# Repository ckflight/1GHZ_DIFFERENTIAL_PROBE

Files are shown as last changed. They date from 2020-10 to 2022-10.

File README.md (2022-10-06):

# 1GHZ DIFFERENTIAL PROBE

Instead of paying a few thousand $ to the unnecessarily expensive probes from tektronix or rigol for daily use, i made a Differential Probe which cost
15$ for 4 layer pcb and 45$ for components and it works just fine.

Mosfet source follower is used as voltage buffer which has 20dB attenuation (1/10) and an opamp subtractor is used at the end. Copper pour at the input of the pcb is removed to reduce input capacitance of the probe for high speed signals. 2 passive LPF is used at the output of Switching Regulator which is generating ripple noise. Also input power from the USB Connector is filtered with 180 Ohm Ferrite Bead which is the input of the Switching Regulator. This way of filtering
is the best way of reducing ripple noise and switching peaks of the regulator. However using second LDO Regulator to filter out instead of using switching regulator is the best option for power filtering which means better high speed signal performance.

Design needs usb input power for powering the circuit and 50 Ohm SMA connector
is used. BNC 50 Ohm feedthrough connector can be used for connection to Oscilloscope if it does not have 50 Ohm option.

1 GHz

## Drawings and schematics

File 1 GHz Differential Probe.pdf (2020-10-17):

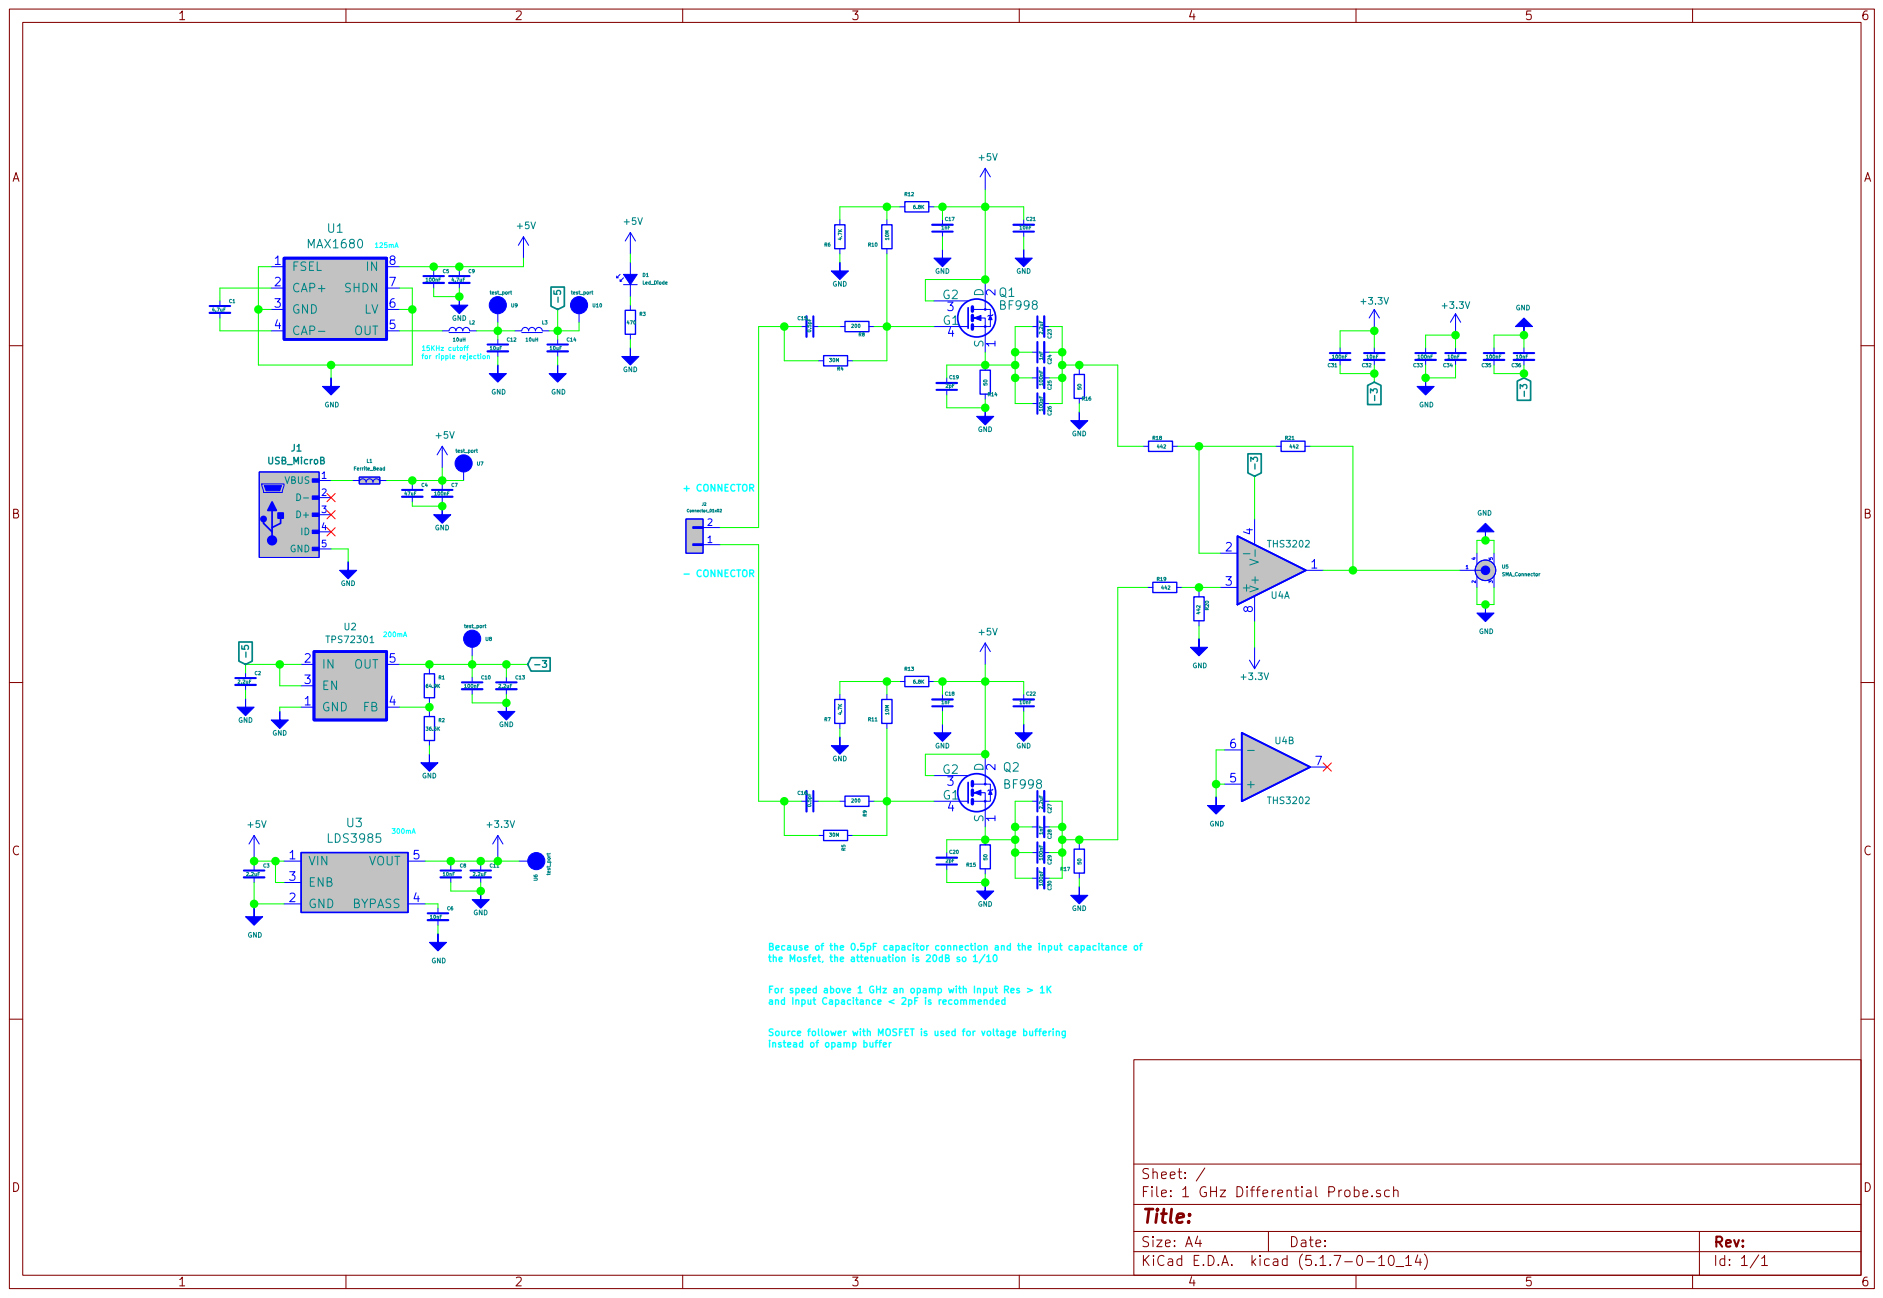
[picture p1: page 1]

15KHz cutoff for ripple rejection

the Mosfet, the attenuation is 20dB so 1/10

Source follower with MOSFET is used for voltage buffering
instead of opamp buffer

Id: 1/1 Title: File: 1 GHz Differential Probe.sch Sheet: /

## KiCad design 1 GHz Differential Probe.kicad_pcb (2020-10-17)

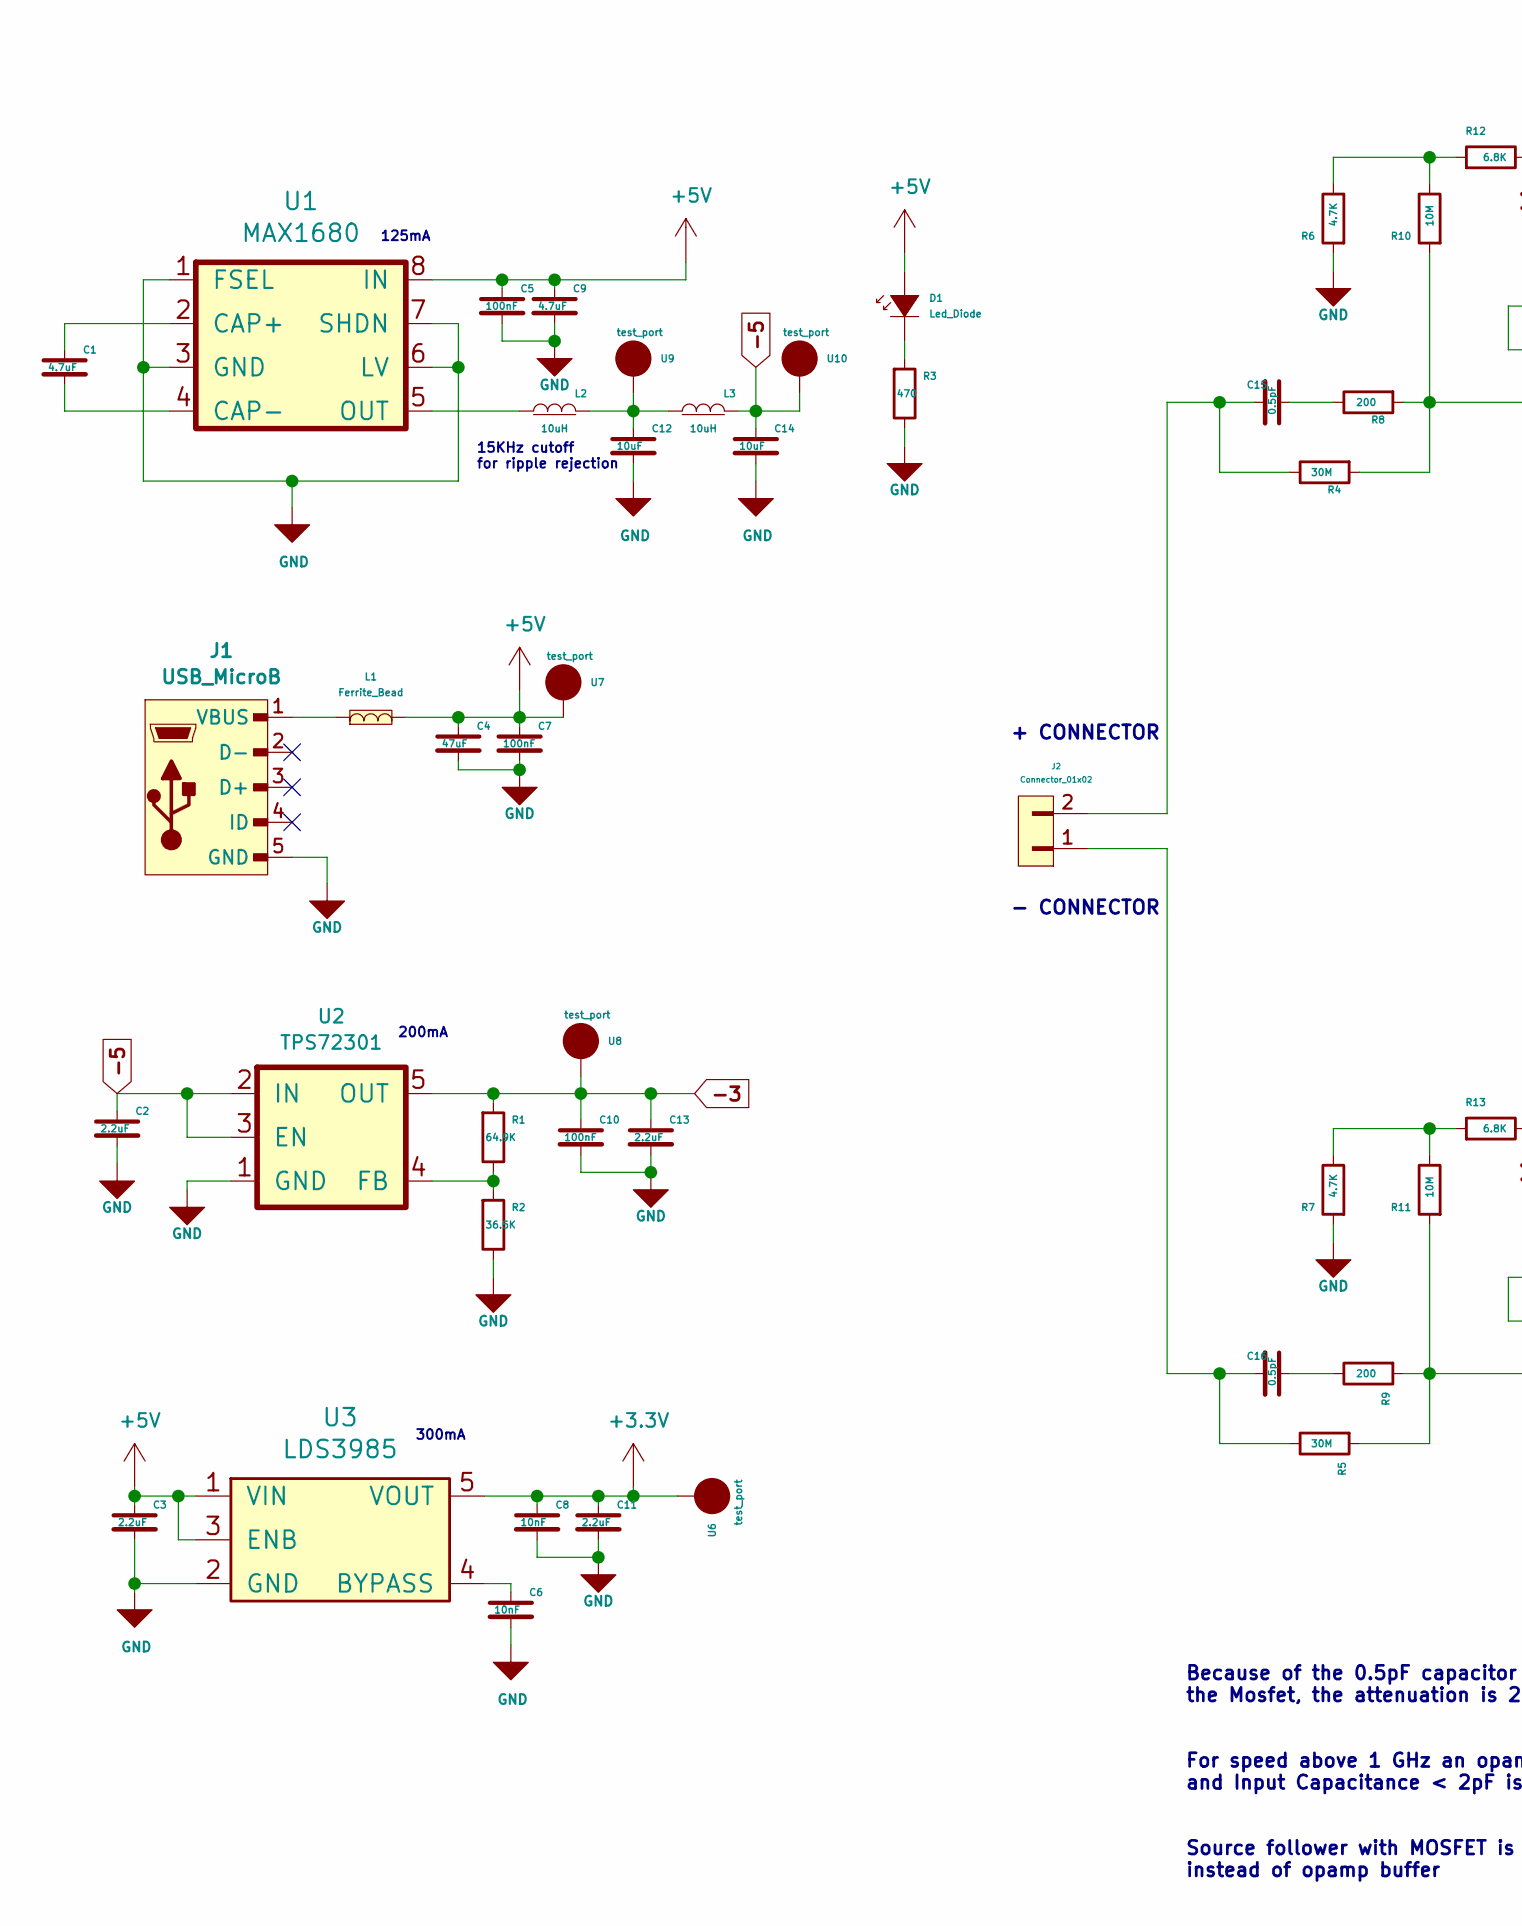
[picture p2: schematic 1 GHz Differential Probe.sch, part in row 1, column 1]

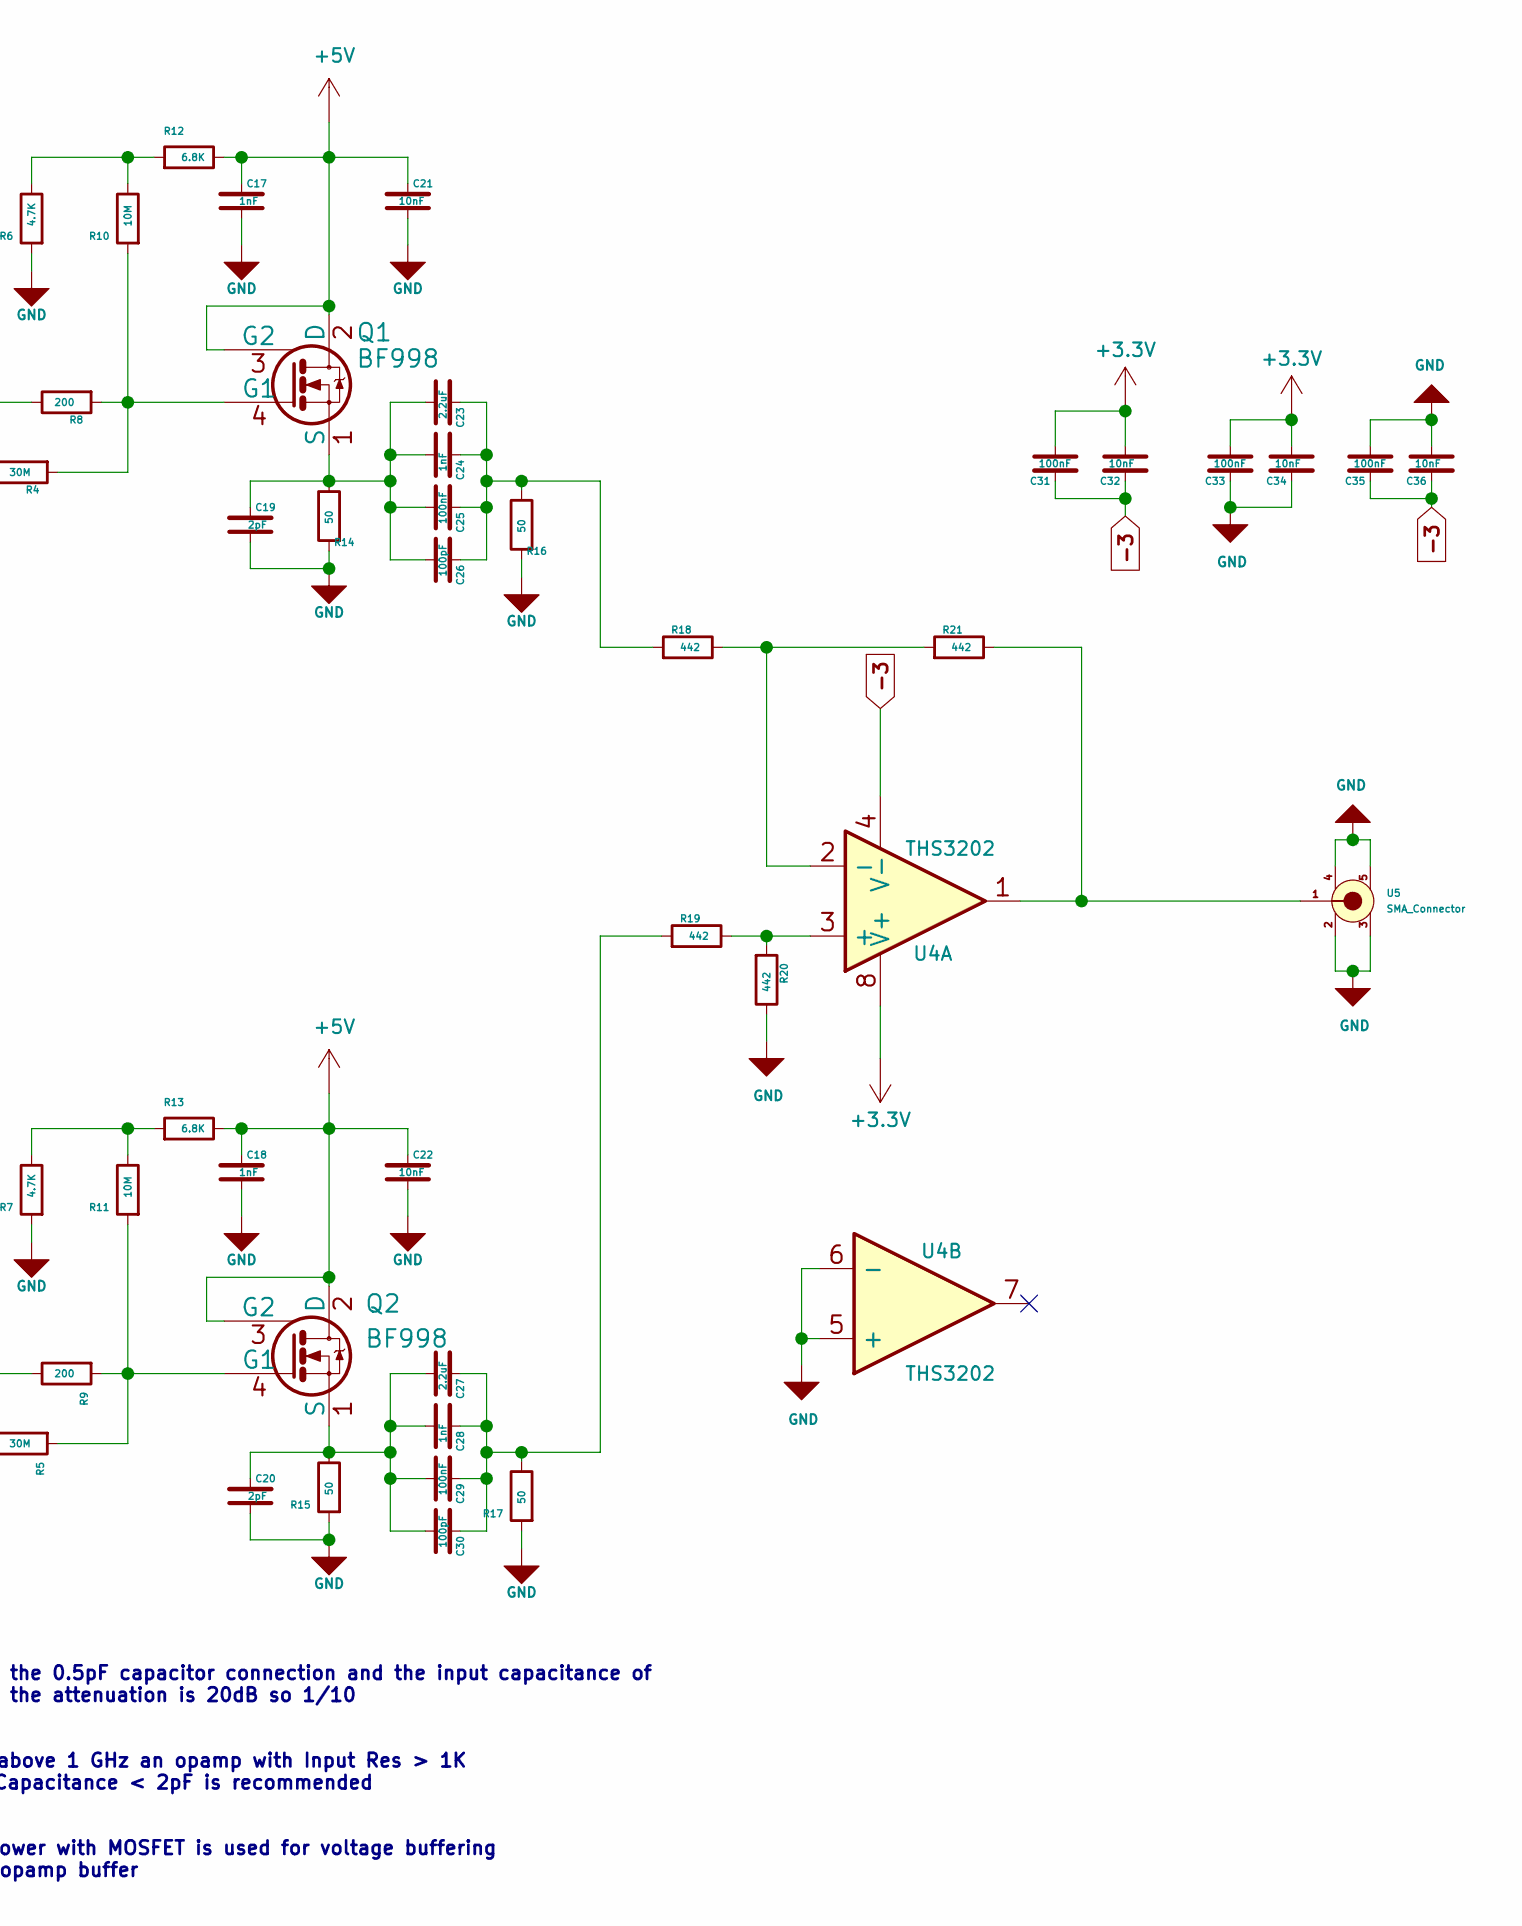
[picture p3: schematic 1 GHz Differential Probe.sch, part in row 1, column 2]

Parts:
C1, C9: 4.7uF; SMD_0603
C2, C3, C11, C13, C23, C27: 2.2uF; SMD_0402
C4: 47uF; SMD_0805
C5, C7, C10, C25, C29, C31, C33, C35: 100nF; SMD_0402
C6, C8, C21, C22, C32, C34, C36: 10nF; SMD_0402
C12, C14: 10uF; SMD_0603
C15, C16: 0.5pF; SMD_0402
C17, C18, C24, C28: 1nF; SMD_0402
C19, C20: 2pF; SMD_0402
C26, C30: 100pF; SMD_0402
D1: Led_Diode; Diode_0603
J1: USB_MicroB; USB_MicroB_TH
J2: Connector_01x02; PinHeader_1x2_P2.5mm
L1: Ferrite_Bead; SMD_0805
L2, L3: 10uH; SMD_0805
Q1, Q2: BF998; SOT143
R1: 64.9K; SMD_0402
R2: 36.5K; SMD_0402
R3: 470; SMD_0402
R4, R5: 30M; SMD_0805
R6, R7: 4.7K; SMD_0402
R8, R9: 200; SMD_0402
R10, R11: 10M; SMD_0603
R12, R13: 6.8K; SMD_0402
R14, R15, R16, R17: 50; SMD_0402
R18, R19, R20, R21: 442; SMD_0402
U1: MAX1680; SO8_3.9X4.9mm_P1.27mm
U2: TPS72301; SOT23_5
U3: LDS3985; SOT23_5
U4: THS3202; VSSOP_8_3x3mm_P0.65mm
U5: SMA_Connector
U6, U7, U8, U9, U10: test_port; SolderPad_1_1.2mm_SMD_Circle

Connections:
+3V3: C8.1, C11.1, C31.1, C32.1, C33.1, C34.1, U3.5 (VOUT), U4.8 (V+), U6.1
+5V: C3.1, C4.1, C5.1, C7.1, C9.1, C17.2, C18.2, C21.2, C22.2, D1.2 (A), L1.2, Q1.2 (D), Q1.3 (G2), Q2.2 (D), Q2.3 (G2), R12.2, R13.2, U1.8 (IN), U3.1 (VIN), U3.3 (ENB), U7.1
-3: C10.1, C13.1, C31.2, C32.2, C35.2, C36.2, R1.1, U2.5 (OUT), U4.4 (V-), U8.1
-5: C2.1, C14.1, L3.2, U2.2 (IN), U2.3 (EN), U10.1
GND: C2.2, C3.2, C4.2, C5.2, C6.2, C7.2, C8.2, C9.2, C10.2, C11.2, C12.2, C13.2, C14.2, C17.1, C18.1, C19.1, C20.1, C21.1, C22.1, C33.2, C34.2, C35.1, C36.1, J1.5 (GND), R2.2, R3.2, R6.1, R7.1, R14.1, R15.1, R16.1, R17.1, R20.2, U1.1 (FSEL), U1.3 (GND), U1.6 (LV), U1.7 (SHDN), U2.1 (GND), U3.2 (GND), U4.5 (+), U4.6 (-), U5.2, U5.3, U5.4, U5.5
unnamed: C1.1, U1.2 (CAP+)
unnamed: C1.2, U1.4 (CAP-)
unnamed: C6.1, U3.4 (BYPASS)
unnamed: C12.1, L2.2, L3.1, U9.1
unnamed: C15.1, R8.2
unnamed: C15.2, J2.2, R4.2
unnamed: C16.1, R9.2
unnamed: C16.2, J2.1, R5.2
unnamed: C19.2, C23.1, C24.1, C25.1, C26.1, Q1.1 (S), R14.2
unnamed: C20.2, C27.1, C28.1, C29.1, C30.1, Q2.1 (S), R15.2
unnamed: C23.2, C24.2, C25.2, C26.2, R16.2, R18.1
unnamed: C27.2, C28.2, C29.2, C30.2, R17.2, R19.1
unnamed: D1.1 (K), R3.1
unnamed: J1.1 (VBUS), L1.1
unnamed: L2.1, U1.5 (OUT)
unnamed: Q1.4 (G1), R4.1, R8.1, R10.1
unnamed: Q2.4 (G1), R5.1, R9.1, R11.1
unnamed: R1.2, R2.1, U2.4 (FB)
unnamed: R6.2, R10.2, R12.1
unnamed: R7.2, R11.2, R13.1
unnamed: R18.2, R21.1, U4.2 (-)
unnamed: R19.2, R20.1, U4.3 (+)
unnamed: R21.2, U4.1, U5.1

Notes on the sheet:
+ CONNECTOR
- CONNECTOR
Because of the 0.5pF capacitor connection and the input capacitance of the Mosfet, the attenuation is 20dB so 1/10
For speed above 1 GHz an opamp with Input Res > 1K and Input Capacitance < 2pF is recommended
15KHz cutoff for ripple rejection
125mA
Source follower with MOSFET is used for voltage buffering instead of opamp buffer
200mA
300mA

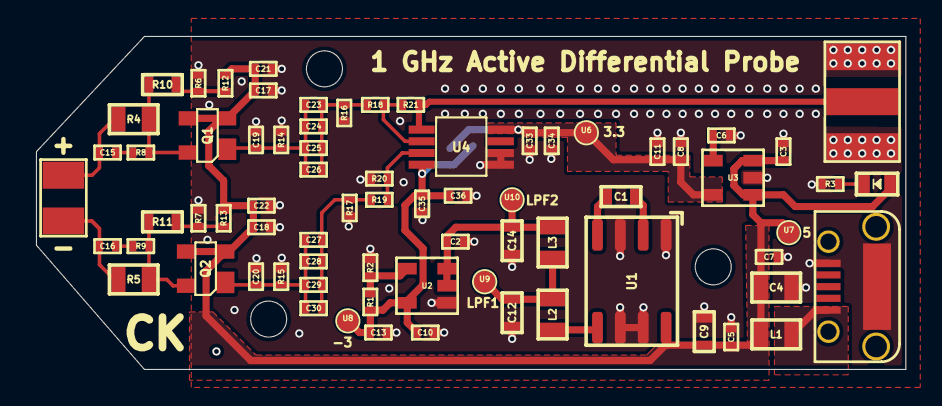
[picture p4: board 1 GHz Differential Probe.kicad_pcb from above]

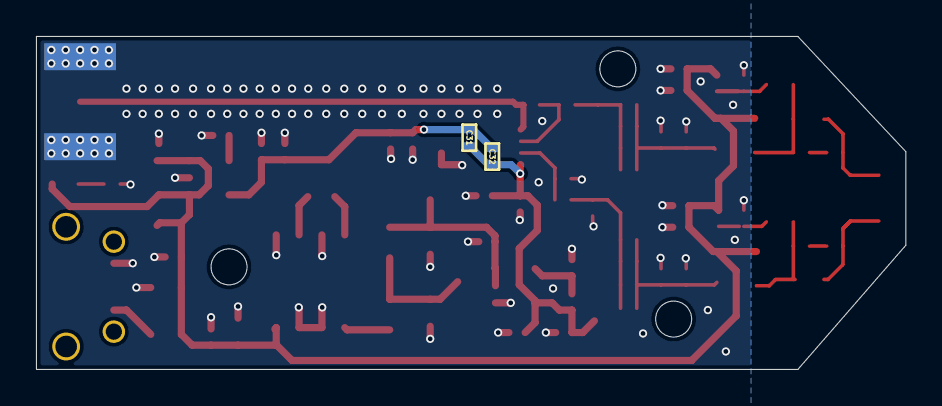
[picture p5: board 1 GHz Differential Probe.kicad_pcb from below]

Board: 4 copper layers, 48.3 x 18.5 mm, 75 parts (2 on the bottom side), 28 nets.
